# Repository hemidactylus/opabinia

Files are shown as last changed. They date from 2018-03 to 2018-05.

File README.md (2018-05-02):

# Opabinia

A system to count people entering/exiting a room,
made with a Raspberry Pi, a couple of proximity sensors, some software and lots of love.

## Overview

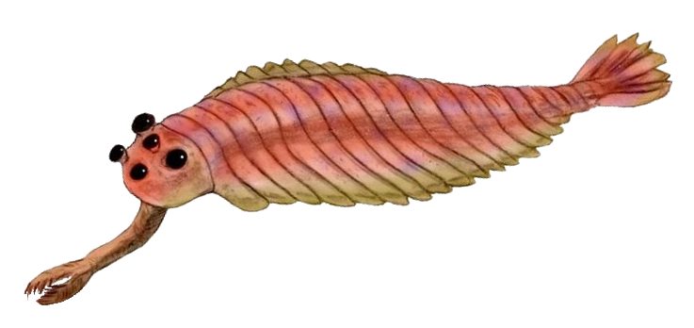
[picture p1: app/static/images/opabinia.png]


Proximity sensors (HC-SR04), attached to a Raspberry Pi, track the passage of people in front of it;
software running on the RPi keeps the counts and offers, in the local network, a simple Web interface
to keep an eye on the counts.

## Ingredients

### Required material

Opabinia is made with the following hardware:
  - a Raspberry Pi 2 B Quad Core CPU 900 MHz, 1 GB RAM
  - a RPi case for aesthetics (_optional_)
  - a microSD card with at least 4 GB space
  - an 802.11g/b/n USB dongle (_for WiFi connectivity_)
  - two proximity sensors of type HC-SR04
  - five LEDs
  - resistors: 5 x 220 Ohm, 2 x 470 Ohm, 2 x 330 Ohm
  - solid-core wiring (AWG 22, ideally)
  - eight female-female dupont cables (to connect the sensors to the board)
  - breakout pins (8x1 male, 20x2 female)
  - some kind of breadboard, e.g. a 8 x 12cm double side prototype pcb breadboard
  - holders to keep the two sensors in place, e.g. a soldering helping hand is a good solution (as pictured below)

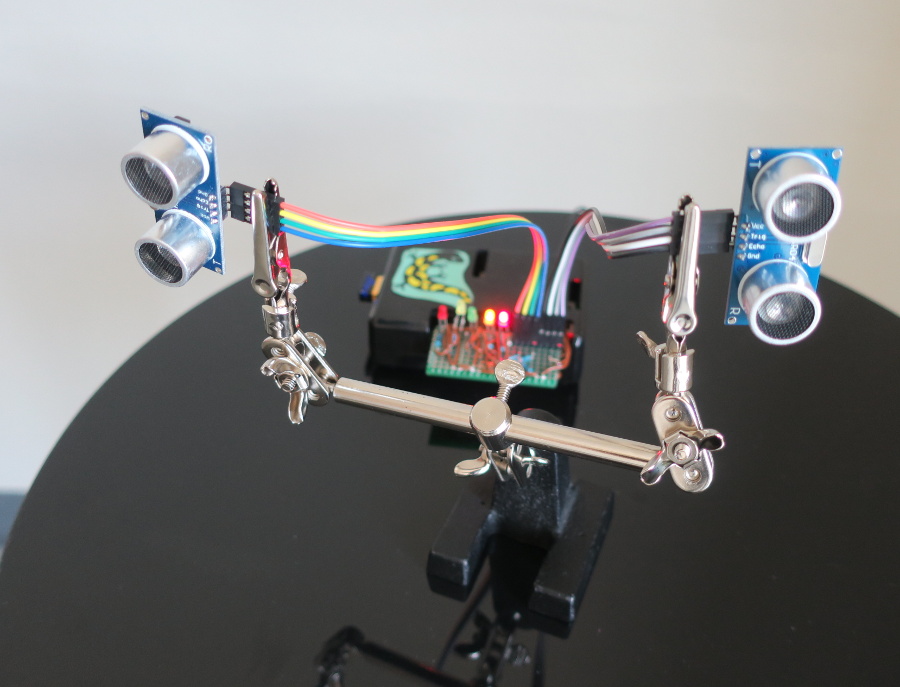
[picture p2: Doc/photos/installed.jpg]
Installed Opabinia


### Schematics

_Note_: there is a [dedicated page](Doc/circuit.md) about fitting the schematics into
an actual layout.

The circuit layout is as follows:

Circuit schematics

The Fritzing file for the above image is in `Doc/schematics`; however, due (probably)
to the sloppy way three-wire junctions are made, it may open improperly.

Moreover, the Fritzing project makes use of a custom part (`HC-SR04.fzpz`)
for the proximity sensor, which can be obtained
and imported [here](http://fritzing.org/projects/hc-sr04-project/).

### Software components

The collected data goes to a sqlite database file: the measurement service, which wraps
a Python (2.7) script (that runs as `root`), writes to it when it detects some events through
the sensors; the web application (running as user `pi`) reads from sqlite and prepares the data
for the web UI.

The web application is a Python Flask application, served by `nginx` through the `uWSGI`
reverse proxy; it is made available in the local network (if the router policies allow
for it and the magic of `DHCP` works).

Additionally, provided the Avahi daemon on the RPi plays nice with the local network,
the app becomes available not only as `http://IP_ADDRESS/`, but also at the address
`http://HOSTNAME.local` (e.g. [`http://pimpa.local/`](http://pimpa.local)).
_Disclaimer_ : for reasons still unclear to
me, this sometimes works and sometimes doesn't, in a rather whimsical way. In the
worst case one can issue a portscan command and figure out the local IP address
of the RPi, whose ssh port 22 is open: that is, with the proper CIDR range for the
local network,

    nmap -p 22 --open -sV 192.168.1.0/24

## Software Installation

### Setting up and provisioning the RPi

Get (and unzip) the image of a Raspbian build for burning onto the SD card.
To save on disk space,
mind that [RaspbianLite](https://www.raspberrypi.org/downloads/raspbian/)
is enough (here it is assumed that Raspbian Stretch Lite is used, which
uses systemd; for older builds, based on systemv, see the note below). Once in possession
of the image, for instance `2017-11-29-raspbian-stretch-lite.img`, burn it from the
PC (without messing up the destination device name, please):

    sudo dd bs=4M if=2017-11-29-raspbian-stretch-lite.img of=/dev/mmcblk0  status=progress conv=fsync

To enable ssh access right from the start, create a file called `ssh` (no extension)
in the root folder of the boot partition of the newly-burned card, as suggested
[here](https://hackernoon.com/raspberry-pi-headless-install-462ccabd75d0).

Connect the RPi to the router with a network cable, insert the SD card into the
slot and turn it on. If the DHCP lease went through, the machine's IP address
can be found either by looking at the lease list in the router's interface
or with (a suitably adapted version of) the `nmap` command given above.

Connect via `ssh` to the RPi. _Note_: in some cases one has to purge
old ssh keys from the `known_hosts` file on the PC (as suggested by the
ssh command). Also, if connecting through the `.local` domain, sometimes
the Avahi domain name of a previous lease on the same IP may linger around
for a little while (e.g. in the router lease list).

Once on a shell in the RPi, complete the configuration with the CLI tool

    raspi-config

The following operations are suggested:
  - __changing the password for user `pi`__
  - choosing to login through CLI (as opposed to "already connected on startup")
  - setting the locale (sometimes unknown-locale errors persist, no big deal)
  - in the Advanced settings, choosing to expand the filesystem to fill up all available space
    (which happens on the next reboot)
  - setting the hostname of the RPi (this is important for Avahi. In the following
    it is assumed the hostname `pimpa`
  - setting the 802.11b/g/n networking. Either through `raspi-config` or as explained in next
    paragraph
  - setting the time zone for the OS to match the value found in `app/config.py` (to avoid
    date/time mismatches in the on-page plots). This is done
    again with `raspi-config` (_Localisation options_, then _Change timezone_).

As for the network configuration, assuming the WiFi USB dongle is plugged in and ackowledged
by the RPi, add a block to the file `/etc/wpa_supplicant/wpa_supplicant.conf` similar to:

    network={
        ssid="testing"
        psk=131e1e221f6e06e3911a2d11ff2fac9182665c004de85300f9cac208a6a80531
    }

where, as detailed [here](https://www.raspberrypi.org/documentation/configuration/wireless/wireless-cli.md),
the `psk` value is the result of running `wpa_passphrase SSID PASSWORD`.

Finally, to make all next steps easier, inject the ssh public key of the PC
to the `authorized_keys` file on the RPi.

Now update the RPi system and install some needed software. _Disclaimer_: no virtualenvs
are used in the Python part of Opabinia. This, although a bit contrary to a general sense
of tidiness, avoids a bit of hassle withouth much collateral damage,
considering this machine will probably be dedicated to Opabinia. However, for running and testing on PC
a `requirements.txt` file is provided (which obviously will not include the `pigpio` component:
to emulate the behaviour of the measurement part the script `app/mockMeasurer.py` is provided).

    sudo apt-get update
    sudo apt-get upgrade
    sudo apt-get install nginx

    sudo apt-get install python-pip

    sudo pip install Flask==0.12.2
    sudo pip install uWSGI==2.0.17
    sudo pip install pytz==2018.3
    sudo pip install Flask-Bootstrap==3.3.7.1
    sudo pip install XlsxWriter==1.0.2

Finally, install (as described [here](https://www.raspberrypi.org/forums/viewtopic.php?f=32&t=103752))
the [`pigpiod`](http://abyz.me.uk/rpi/pigpio/pigpiod.html) package by Joan, making it also into a service:

      sudo apt-get install pigpio
      sudo systemctl enable pigpiod.service

### Installing and configuring Opabinia

First clone this repo (or rsync it over) so that there is
the directory `/home/pi/web/Opabinia/` on the RPi.
Make sure `app/measurer.py` and `wsgi_run.py` are given execute
permission, the former in particular for all users.

To set up the web app so that nginx acts as a reverse proxy to it: copy the
site file `Doc/nginx/site-opabinia` into `/etc/nginx/sites-available`,
__remembering to adapt its `server_name` line to the RPi's network configuration__, and
make a symlink thereto in `/etc/nginx/sites-enabled`.
Finally, delete the `default` file found
in `etc/nginx/sites-enabled`.

_Now this would be a good moment to solder and/or wire up the circuitry as
shown in the schematics above. This should be made with the RPi powered off._

To set up both the Flask app and the measurer as system services,
the following two files must be copied into `/etc/systemd/system/`:

    /Doc/systemd/opawebapp.service
    /Doc/systemd/opacounter.service

To start the services:

    sudo systemctl start opawebapp
    sudo systemctl start opacounter

and finally to make them start at each reboot:

    sudo systemctl enable opawebapp
    sudo systemctl enable opacounter

_Note_: these instructions for the system services assume systemd is the init daemon:
in other cases, similar instructions apply, see the note below for Wheezy.

__Sensor configuration__: in most cases, the only settings that might require
some tuning are: (1) the `timeZone` in `config.py`
(refer to [`pytz`](https://pypi.python.org/pypi/pytz) for details on this)
and, accordingly, at the OS level;
(2) the range of distances triggering a positive detection:
they are set (in meters) by changing the two-element array `sensorDistanceRange`
in file `app/config.py` (after which `opacounter` shall be restarted).

### In case of Wheezy Raspbian

On older Raspbian builds (i.e. Wheezy), the systemd part is replaced by systemV scripts.
Sample scripts, replacing the systemd ones, are provided in the `Doc/systemV` directory
(make sure they are made executable with `chmod u+x`).

### Relevant links
  
[Setting up a python Flask web-app on a RPi with uWSGI and Python](https://iotbytes.wordpress.com/python-flask-web-application-on-raspberry-pi-with-nginx-and-uwsgi/)

[SystemV init scripts](https://blog.frd.mn/how-to-set-up-proper-startstop-services-ubuntu-debian-mac-windows/)

(the other) [Opabinia](http://www.prehistoric-wildlife.com/species/o/opabinia.html)

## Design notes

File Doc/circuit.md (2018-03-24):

# Opabinia - circuit layout

This page details a little how the circuit was made to fit
onto a 27 x 52 mm prototype pcb and soldered to become a
board ready to plug on the RPi's 20x2 GPIO pin set.

The pcb is sawed off to achieve the desired dimension, with
20x10 holes. Two sets of breakout pins will be soldered to
the board: a 20x2 female block for the RPi GPIO, and an
8x1 male set for the two proximity sensors.

The female block faces "downwards" and the male block "upward",
as in the following sketch:

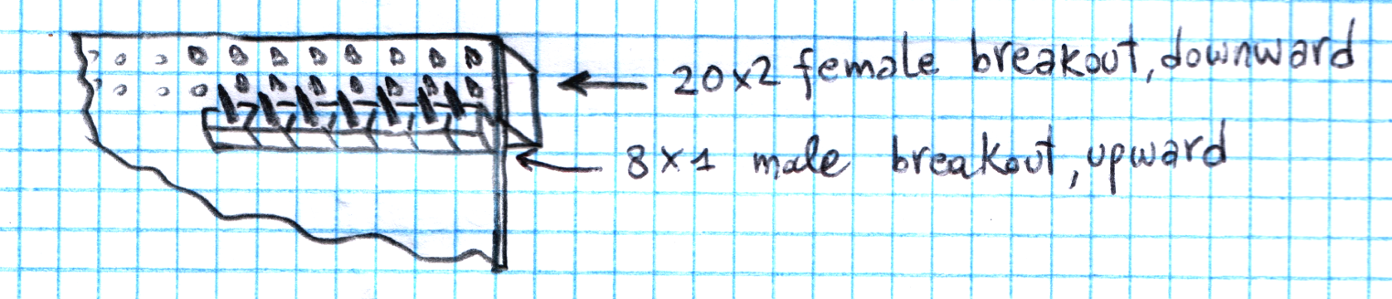
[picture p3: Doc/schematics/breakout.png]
Breakout sketch


The precise location of each pin, each connection and each blob of tin
is detailed here below. One should be careful to think carefully the right order
when soldering (e.g. first the ground row, then the echo resistors, then the LED
sets, then the male breakout and finally the female breakout).

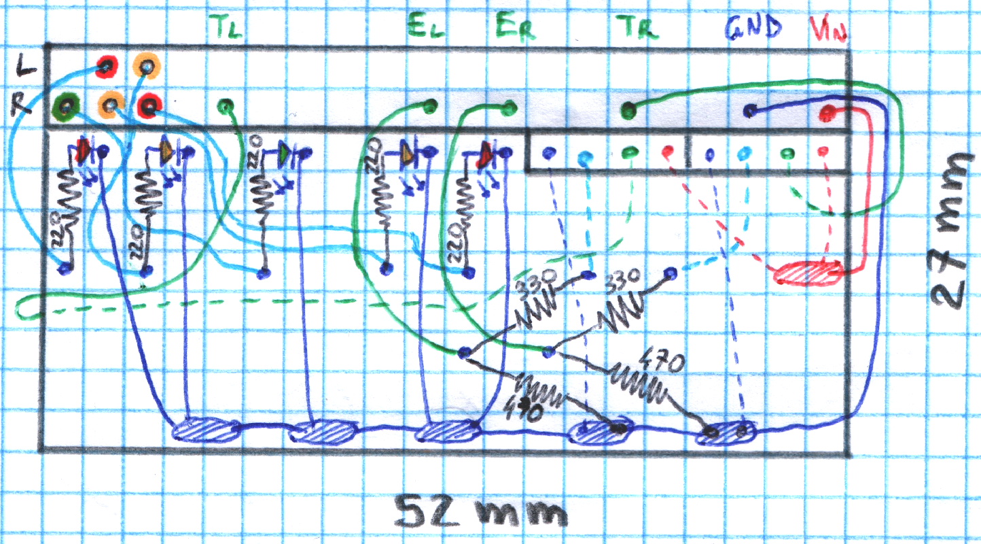
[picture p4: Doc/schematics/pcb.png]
PCB Schematics


## The result

Soldered board:

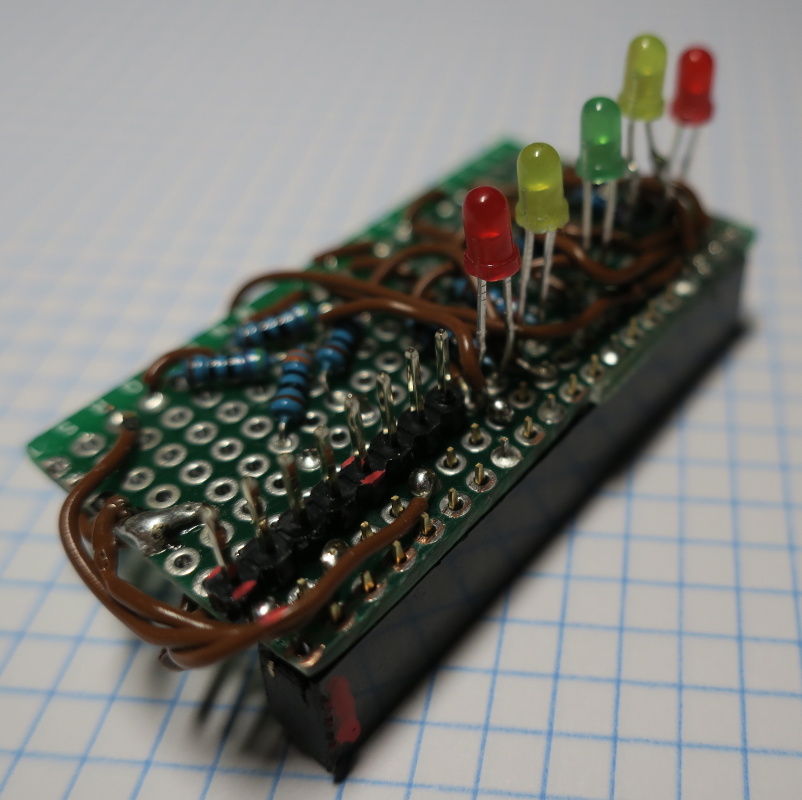
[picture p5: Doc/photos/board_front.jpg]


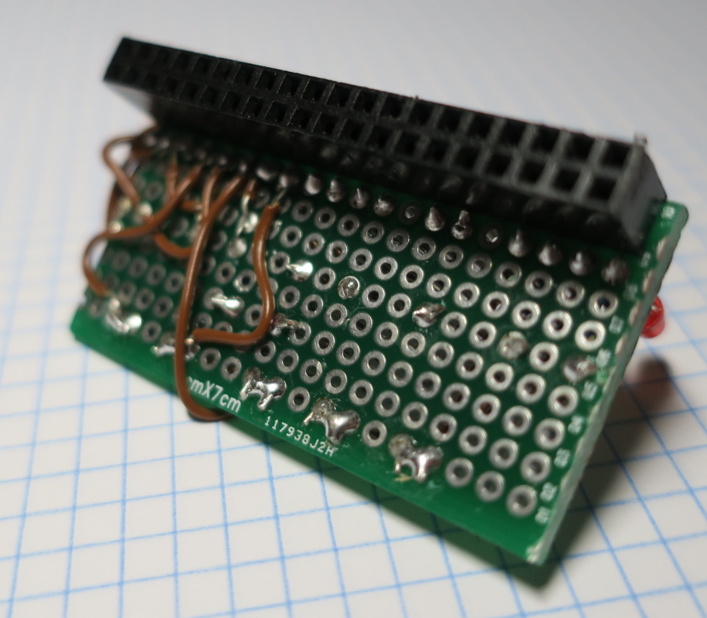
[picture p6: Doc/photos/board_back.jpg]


Plugged on the RPi:

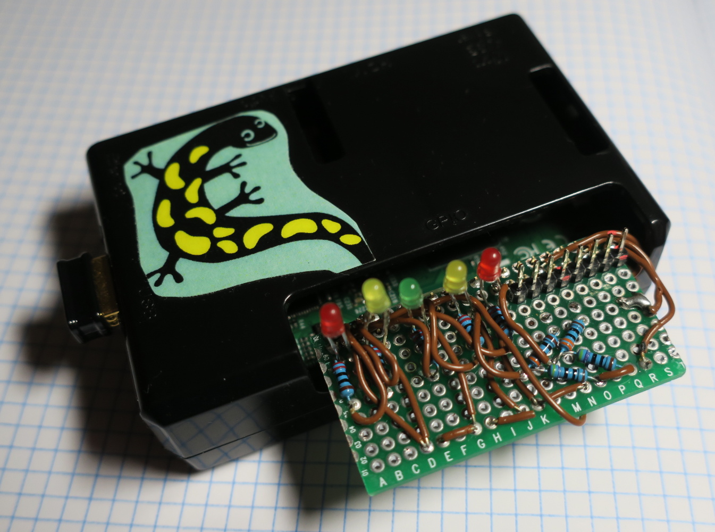
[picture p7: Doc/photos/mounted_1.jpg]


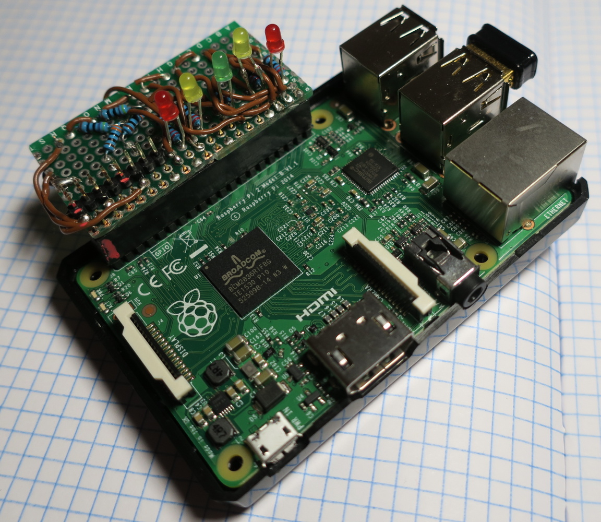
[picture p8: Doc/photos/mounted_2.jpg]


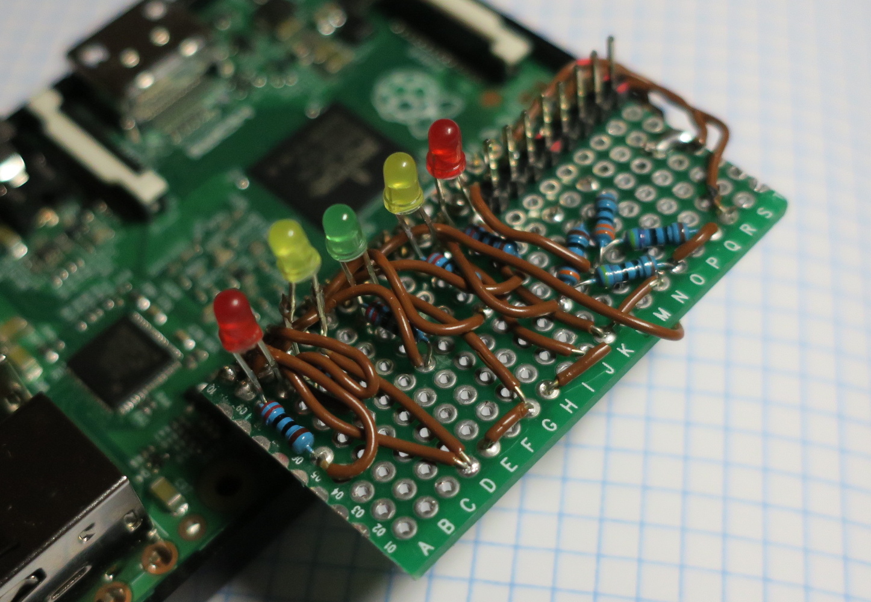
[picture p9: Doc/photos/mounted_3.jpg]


## Further suggestion

One could restructure the above layout to make the board still
fit as an add-on to the RPi, but inward-facing, i.e. almost completely
hidden into the Raspberry case (except for the sensor pins and the LEDs).

This exercise is left to the reader (_because that was the original plan,
but due to a major overlooking I ended up with the board orientation as
shown and now I will happily stick to it_).

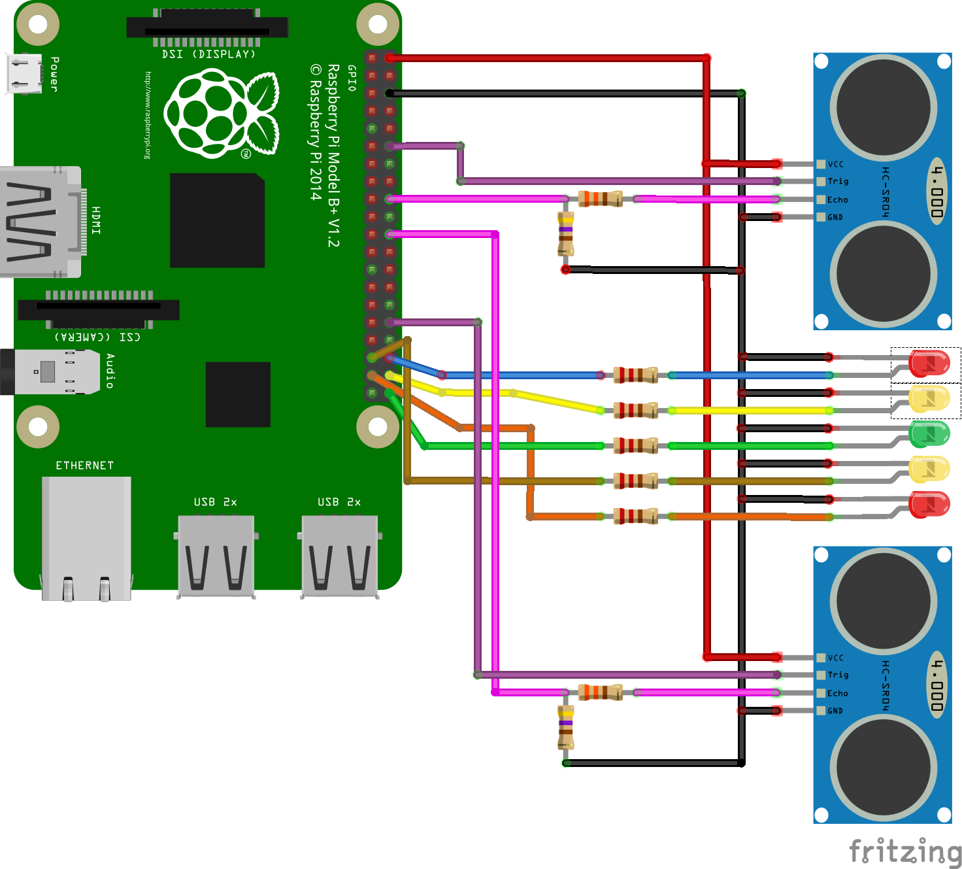
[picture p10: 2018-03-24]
Doc/schematics/opabinia_bb.png

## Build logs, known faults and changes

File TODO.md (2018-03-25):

# TODO

Plots:
  - css properly for all styles
      - the font weight/colors to the various numbers in the html

  - Clean up the mess with using y-scales and x-scales in a hybrid way wrt offsets etc

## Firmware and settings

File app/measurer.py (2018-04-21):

#!/usr/bin/python

'''
    measurer.py : the independent stand-alone forever-running
    script that measures and updates the DB

    In order to use the GPIO pins, this must run as root

'''

import time
import pigpio

from config import (
    dbName,
    #
    sensorPins,
    innerSensor,
    #
    sensorReadFrequency,
    sensorDistanceRanges,
    sensorDebounceTime,
    sensorRefractoryTime,
    sensorPassageWindow,
    #
    sensorDampRate,
    sensorThresholdFactor,
    #
    ledPins,
)
from dboperations import (
    checkAndOpenDatabase,
    dbOpenDatabase,
    dbSaveRow,
)
from DistanceSensor import (
    DistanceSensor,
    DebouncedSensor,
)

if __name__=='__main__':

    print('Init.')
    db=checkAndOpenDatabase(dbName)
    pi=pigpio.pi()

    distancers=[
        DistanceSensor(pi,sPins['trigger'],sPins['echo'])
        for sPins in sensorPins
    ]
    debounceds=[
        DebouncedSensor(
            sensorDistanceRange,
            sensorDebounceTime,
            distancer,
            sensorRefractoryTime,
            avgDampRate=sensorDampRate,
            avgThresholdFactor=sensorThresholdFactor,
        )
        for distancer,sensorDistanceRange in zip(
            distancers,
            sensorDistanceRanges,
        )
    ]

    # led setup
    for ledPin in (ledPin for ledPinGroup in ledPins.values() for ledPin in ledPinGroup):
        pi.set_mode(ledPin,pigpio.OUTPUT)
        pi.write(ledPin,0)

    # callbacks to register in the debounceds
    def debouncedCallback(debIndex,debounceds=debounceds,pi=pi,ledPins=ledPins,db=db):
        '''
            debIndex is the index in 'debounced' of who triggered the callback
        '''
        thisDeb=debounceds[debIndex]
        # if this sensor went UP and the other one went UP in a recency timewindow,
        # call it a +/- 1 and commit it.
        if thisDeb.debStatus:
            activationDelay=thisDeb.lastDebouncedHigh - debounceds[1-debIndex].lastDebouncedHigh
            if activationDelay <= sensorPassageWindow[1] and activationDelay >= sensorPassageWindow[0]:
                # +/-1 event detected. Direction is determined
                # based on which sensor was this, and what is the 'inside'-facing sensor.
                direction=(2*debIndex-1)*(2*innerSensor-1)
                dbSaveRow(db,{'count':direction,'abscount':1})
                db.commit()
        #
        handleBaselineLed()
        pi.write(ledPins['detect'][debIndex],thisDeb.debStatus)

    def changeCallback(debIndex,debounceds=debounceds,pi=pi,ledPins=ledPins,db=db):
        thisDeb=debounceds[debIndex]
        handleBaselineLed()
        pi.write(ledPins['signal'][debIndex],thisDeb.instaStatus)

    def handleBaselineLed(debounceds=debounceds,ledPins=ledPins):
        tTime=time.time()
        noActivity=not any(deb.instaStatus or deb.debStatus for deb in debounceds)
        pi.write(ledPins['baseline'][0],noActivity * (int(tTime*2) % 2) )

    for dIndex,deb in enumerate(debounceds):
        deb.onDebouncedChange(lambda d=dIndex: debouncedCallback(d))
        deb.onChange(lambda d=dIndex: changeCallback(d))

    while True:
        for deb in debounceds:
            deb.update()
            handleBaselineLed()
            time.sleep(sensorReadFrequency)

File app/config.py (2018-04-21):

'''
  config.py - publicly available things
'''

import os
from datetime import timedelta

basedir = os.path.abspath(os.path.dirname(__file__))

dbName = os.path.join(basedir,'database','opabinia.db')

timeZone='Europe/Rome'

dateFormat='%Y-%m-%d'
niceDateFormat='%B %d, %Y'
fileNameDateFormat='%Y_%m_%d_%H_%M_%S'

# web app settings
barSeconds=30*60 # for the histogram on 'Flux' page
maxNumCounterEntries=500   # above this many counter
                            # entries in one day, the
                            # shortest-lived are pruned away cleanly

# sensor setup
#    (Left=0 and Right=1 sensor pin setup.
#     L/R refer to someone looking at the sensors).
sensorPins=[
    {
        'trigger': 12,
        'echo':    25,
    },
    {
        'trigger': 18,
        'echo':    24,
    },
]
# which way is 'entering' (i.e. +1)?
innerSensor=0 # i.e. the L one is the one closer to 'in'
# sensor response setup
sensorReadFrequency=0.002           # seconds
sensorDistanceRanges=[              # meters: min/max, per sensor
    [0.25,0.95],
    [0.25,0.95],
]
sensorDebounceTime=0.02             # seconds
sensorRefractoryTime=0.1            # seconds
sensorPassageWindow=[0.025,0.6]     # seconds
# expwindow sensor settings
sensorDampRate=0.8
sensorThresholdFactor=0.2
# status-signaling LEDs
ledPins={
    'baseline': [21],       # baseline, operation (green) - only one
    # these are [R, L] in the same way as the sensorPins above
    'signal':   [19, 20],   # instantaneous measurement (yellow)
    'detect':   [26, 16],   # debounced status (red)
}

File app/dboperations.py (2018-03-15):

'''
    dboperations.py : higher-level stuff built on top of the dbtools
'''

import os
import stat
from datetime import datetime, date

from dbtools import (
    dbOpenDatabase,
    prepareWhereClause,
    dbRetrieveAllRecords,
    dbRetrieveRecordByKey,
    dbAddRecordToTable,
    dbDeleteTable,
    dbCreateTable,
)

from dateutils import (
    findPreviousMidnight,
    localiseDate,
)

from config import dateFormat

from dbschema import dbTablesDesc

def setRWAttributeForAll(filename):
    '''
        Set rw-rw-rw attribute to database file
    '''
    attrConstant=stat.S_IWUSR | stat.S_IWGRP | stat.S_IWOTH | stat.S_IRUSR | stat.S_IRGRP | stat.S_IROTH
    os.chmod(filename, attrConstant )

def checkAndOpenDatabase(dbName):
    if not os.path.isfile(dbName):
        print('[checkAndOpenDatabase] Going to create DB "%s"!' % dbName)
        db=dbOpenDatabase(dbName)
        for tName, tContents in dbTablesDesc.items():
            try:
                retVal=dbDeleteTable(db, tName)
            except:
                pass
            retVal=dbCreateTable(db, tName, tContents)
        db.commit()
        setRWAttributeForAll(dbName)
        print('Done.')
    return dbOpenDatabase(dbName)

def dbGetRows(db,reqDate):
    whereClause='date = \'%s\'' % reqDate.strftime(dateFormat)
    return dbRetrieveAllRecords(db,'counts',whereClause=whereClause)

def dbSaveRow(db, record):
    finalRecord={k :v for k,v in record.items()}
    now=datetime.utcnow()
    finalRecord['date']=localiseDate(now).date()
    finalRecord['time']=now
    dbAddRecordToTable(db,'counts',finalRecord)

def dbSaveHistory(db, record):
    '''
        the history item should be completely done by this time
    '''
    dbAddRecordToTable(db,'history',record)

def dbGetHistory(db, date):
    return dbRetrieveRecordByKey(db,'history',date)

def integrateRows(db, reqDate, cumulate=True):
    '''
        sorts and integrates (over time) the rows
        pertaining to the requested date, with
        a zero integration constant.

        if cumulate, the whole cumsum is returned;
        otherwise, only the final sum.

        * upon a cumulate=false call, a day that is old enough
          can be cached for speedy lookup later.

    '''
    #
    summedKeys={'count','abscount'}
    ini={k:0 for k in summedKeys}
    insFound=0
    ini['ins']=insFound
    if cumulate:
        ini['time']=findPreviousMidnight(reqDate)
        ini['sign']=0
        results=[ini]
    else:
        # check if on cache
        cacheable=reqDate < localiseDate(datetime.utcnow()).date()
        if cacheable:
            cachedDoc=dbGetHistory(db,{'date':reqDate})
            if cachedDoc is not None:
                return cachedDoc
        #
        maxFound=0
    #
    whereClause='date = \'%s\'' % reqDate.strftime(dateFormat)
    rowCursor=dbRetrieveAllRecords(db,'counts',whereClause=whereClause)
    #
    for doc in rowCursor:
        ini={
            k: ini.get(k,0)+doc.get(k,0)
            for k in summedKeys
        }
        insFound=insFound+(1 if doc['count']>0 else 0)
        ini['ins']=insFound
        if cumulate:
            ini['time']=doc['time']
            ini['sign']=doc['count']
            results.append(ini)
        else:
            maxFound=max(maxFound,ini['count'])
    if cumulate:
        return results
    else:
        result={k:v for k,v in ini.items()}
        result['max']=maxFound
        result['date']=reqDate
        # cache to 'history' if old enough
        if cacheable:
            dbSaveHistory(db,result)
            db.commit() # it would be nice to move this to a datelist-level!
        #
        return result

def dbGetDateList(db,startDate=None):
    #
    if startDate is not None:
        whereClause='date >= \'%s\'' % startDate.strftime(dateFormat)
    else:
        whereClause=None
    #
    return sorted(
        tp[0]
        for tp in db.cursor().execute(
            'SELECT DISTINCT(date) FROM counts %s;' % (
                ''
                if whereClause is None
                else ' WHERE %s' % whereClause
            )
        )
    )

if __name__=='__main__':
    from config import dbName
    from datetime import datetime

    db=checkAndOpenDatabase(dbName)
    print('\n'.join(map(str,integrateRows(
        db,
        zeroDate=datetime(2018,3,4,12,58),
        startDate=datetime(2018,3,4,13,39),
        endDate=datetime(2018,3,4,13,50),
    ))))

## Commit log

2018-03-05 Fixes to the README
    [config.py]
2018-03-05 Fixed a few little things
    [DistanceSensor.py]
2018-03-06 Fixed the proper finding of the most recent midnight
    [dbtools.py, mockMeasurer.py, views.py]
2018-03-09 Added a sample spreadsheet generation and serving
2018-03-10 Measurer logic for two-sensor +-1 detection done
2018-03-10 Moved the debounced sensor class to where it belongs
2018-03-10 Added schematics
    [opabinia.fzz]
2018-03-11 Added 'Ins' to the daily history; fixed an issue with timeBounds
    [config.py, dateutils.py, dboperations.py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]
2018-03-15 Fixed the counts plot and added a column
    [dboperations.py, views.py]
2018-03-15 Fixed the plots for history and flux
    [config.py, dateutils.py, views.py]
2018-03-17 Fixed and polished the base plots
    [views.py]
2018-03-20 Fixed some little things in the endpoints and the link construction
    [dateutils.py, views.py]
2018-03-21 Fixed issues with gutter in counts plot
    [dateutils.py, views.py]
2018-03-23 Fixed an out-of-memory visualisation case with a selective pruning
    [config.py, dateutils.py]
2018-03-24 Finished separating api/endpoints, fixed schematics
    [opabinia.fzz]
2018-03-24 Fixed small bugs in the history view
    [api.py]
2018-03-24 Added pictures and doc on soldering the board
2018-03-24 Fixed sortings and saved some code in spreadsheet generation
    [api.py, dateutils.py, spreadsheets.py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]
2018-04-14 Final tuning of the sensor settings
2018-04-14 Final tuning of the sensor settings 2
2018-04-21 Per-sensor distance range configuration; fixed left/right sensor assignment
    [config.py, measurer.py]
